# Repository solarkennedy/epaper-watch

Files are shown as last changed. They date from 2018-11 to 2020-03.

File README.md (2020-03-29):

# epaper-watch

Originally setup as a watch, this turned into a wall clock:

epaper clock (https://xkyle.com/uploads/epaper_clock.jpg)

It uses a [database of literary quotes](https://xkyle.com/epaper-watch-Cleaning-the-Literary-Quotes-Database/) to display what time it is, highlighting the quote in <font color="red">red</font>.

This project originally started as a wrist watch with battery management and a custom PCB:

epaper watch_prototype (https://xkyle.com/uploads/epaper_watch.jpg)

The wrist watch version was too ambitious and too distracting, so I gave up and just left it as a wall-clock. Originally I took inspiration from this [clock that used a kindle](https://www.instructables.com/id/Literary-Clock-Made-From-E-reader/), but wanted more control over the hardware.

## Hardware

* 2.9inch (296x128 pixels) Waveshare eink [module](https://www.waveshare.com/wiki/2.9inch_e-Paper_Module_(B))
* esp8266 development board
* Picture frame

## Software

* [Source code](https://github.com/solarkennedy/epaper-watch)
* NTP-sourced time
* Ubuntu font
* Literary quotes for (most) minute of the hour

## Usage

It isn't the most accurate or easy to read clock, but it is interesting and looks nice when it has a good quote on it.

The refresh is a bit ugly and could be improved (click for the youtube version):

epaper clock refresh (https://www.youtube.com/watch?v=ptu6fU2wjEg)

The tri-color epaper requires two refresh cycles, one to clear the screen and put down black, then a second pass for the red. See [Ben Krasnow's (Applied Science) notes](https://benkrasnow.blogspot.com/2017/10/fast-partial-refresh-on-42-e-paper.html) on these epaper displays for some interesting low-level technical details on how they work.

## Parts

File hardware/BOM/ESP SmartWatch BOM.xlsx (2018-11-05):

ESP SmartWatch Bill of Materials
Qty | Part | Value | Device | Package | MPN
10 | C1, C2, C4, C5, C6, C7, C8, C9, C10, C11 | 1u | C-USC0603 | C0603 | CL10B105MO8NNWC
7 | C3, C13, C14, C15, C20, C21, C22 | 0.1u | C-USC0603 | C0603 | CL10F104ZO8NNNC
2 | C12, C19 | 4.7u | C-USC0603 | C0603 | CL10A475KP8NNNC
4 | D1, D2, D3, D4 | MBR0530 | MBR0520LT | SOD123 | MBR0530
1 | DISP | 24FLZ-SM2-TB(LF)(SN) | 24FLZ-SM2-TB(LF)(SN) | CON24_1X24_DB_JST | 24FLZ-SM2-TB(LF)(SN)
1 | IC2 | NCP603SN330T1G | NCP603SN330T1G | SOT95P275X110-5N | NCP603SN330T1G
1 | L1 | ASPI-6045S-680M-T | ASPI-6045S-680M-T | ASPI-6045S-680M-T | ASPI-6045S-680M-T
1 | Q1 | FDV305N | MOSFET-NCH | SOT23-3 | FDV305N
1 | Q4 | ZXM61P02FTA | MOSFET-PCH | SOT23-3 | ZXM61P02FTA
1 | R1 | 3R | R-US_R0603 | R0603 | RC0603FR-073R01L
8 | R2, R3, R4, R5, R6, R7, R10, R14 | 10k | R-US_R0603 | R0603 | RC0603FR-0710KL
3 | R11, R12, R13 | 47k | R-US_R0603 | R0603 | RC0603FR-0747KL
1 | U1 | ESP-12F | ESP-12F | ESP-12F | *module*
1 | U2 | MCP73832 | MCP73832 | SOT23-5 | MCP73832T-2ACI/OT
1 | USB1 | ZX62-B-5PA | MICRO-USB-SMD(ZX62-B-5PA) | MICRO-USB | ZX62-B-5PA(33)

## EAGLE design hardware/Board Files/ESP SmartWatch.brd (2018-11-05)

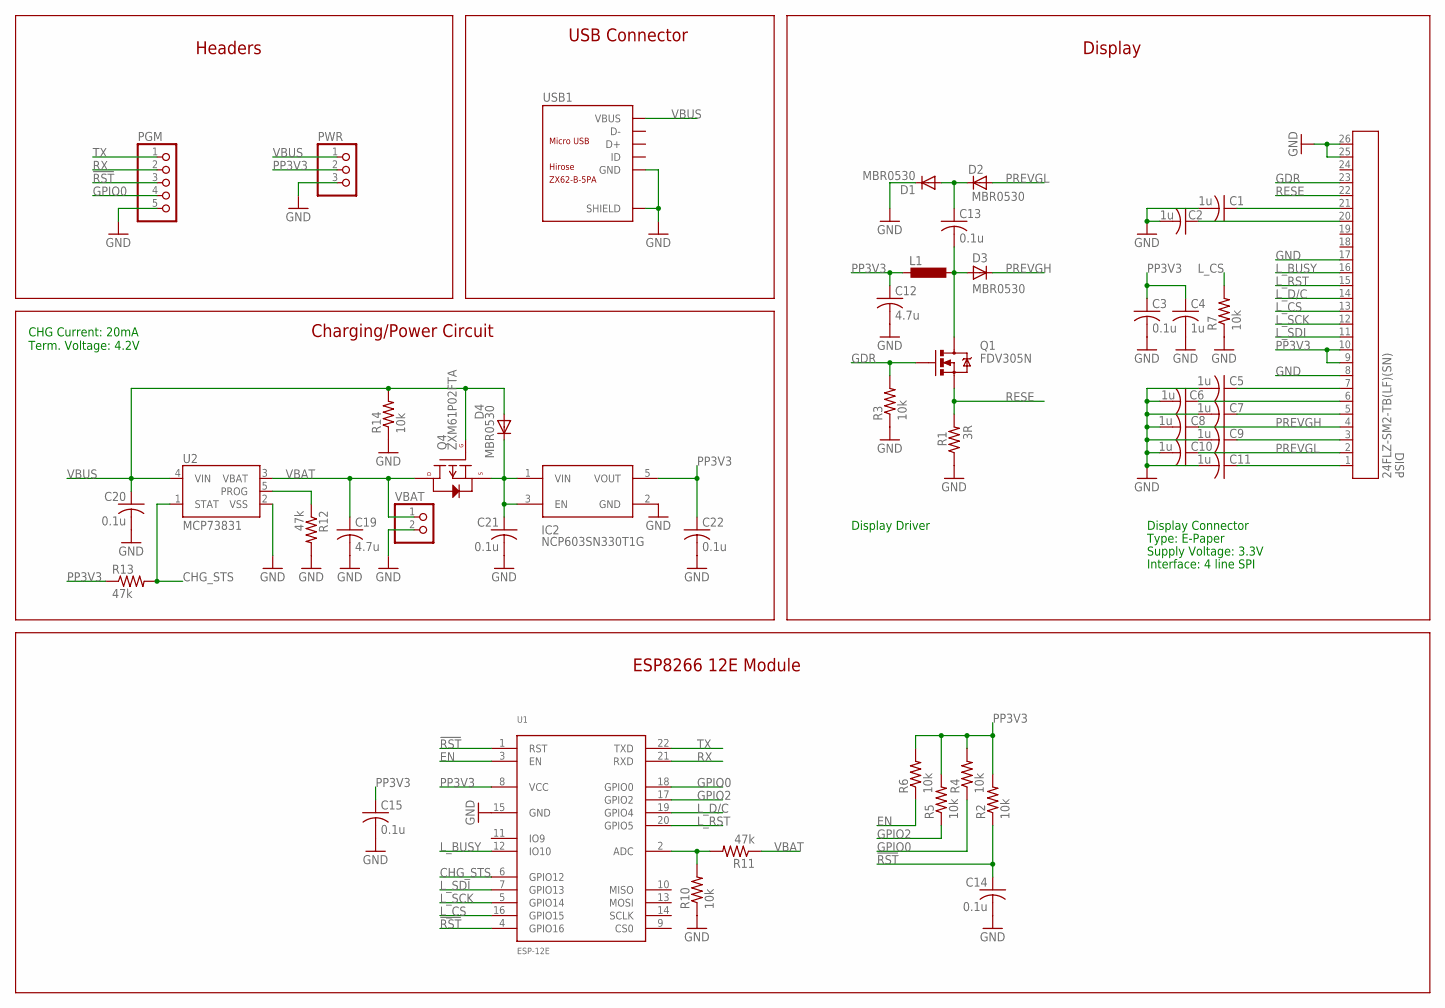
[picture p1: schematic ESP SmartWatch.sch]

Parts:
C1, C2, C4, C5, C6, C7, C8, C9, C10, C11: 1u; C0603
C3, C13, C14, C15, C20, C21, C22: 0.1u; C0603
C12, C19: 4.7u; C0603
D1, D2, D3, D4: MBR0530; SOD123
DISP: 24FLZ-SM2-TB(LF)(SN); CON24_1X24_DB_JST
IC2: NCP603SN330T1G; SOT95P275X110-5N
L1: ASPI-6045S-680M-T
PGM: PINHD-1X05_2.00; 1X05M
PWR: PINHD-1X03_2.00; 1X03M
Q1: FDV305N; SOT23-3
Q4: ZXM61P02FTA; SOT23-3
R1: 3R; R0603
R2, R3, R4, R5, R6, R7, R10, R14: 10k; R0603
R11, R12, R13: 47k; R0603
U1: ESP-12E; ESP-12F
U2: MCP73831; SOT23-5
USB1: ZX62-B-5PA; MICRO-USB5+6P-SMD-0.65-AB
VBAT: PINHD-1X02_2.00; 1X02M

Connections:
!RST: C14.1, PGM.3, R2.1, U1.1 (RST), U1.4 (GPIO16)
CHG_STS: R13.2, U1.6 (GPIO12), U2.1 (STAT)
EN: R6.1, U1.3 (EN)
GDR: DISP.23 (2323), Q1.1 (G), R3.2
GND: C1.2, C2.2, C3.2, C4.2, C5.2, C6.2, C7.2, C8.2, C9.2, C10.2, C11.2, C12.2, C14.2, C15.2, C19.2, C20.2, C21.2, C22.2, D1.C, DISP.8 (88), DISP.17 (1717), DISP.25 (2525), DISP.26 (2626), IC2.2 (GND), PGM.5, PWR.3, R1.1, R3.1, R7.1, R10.1, R12.2, R14.1, U1.15 (GND), U2.2 (VSS), USB1.5 (GND), USB1.P1 (SHIELD), USB1.P2 (SHIELD), USB1.P3_1 (SHIELD), USB1.P3_2 (SHIELD), USB1.P3_3 (SHIELD), USB1.P4_1 (SHIELD), USB1.P4_2 (SHIELD), USB1.P4_3 (SHIELD), USB1.P5 (SHIELD), USB1.P6 (SHIELD), VBAT.2
GPIO0: PGM.4, R4.1, U1.18 (GPIO0)
GPIO2: R5.1, U1.17 (GPIO2)
L_BUSY: DISP.16 (1616), U1.12 (IO10)
L_CS: DISP.13 (1313), R7.2, U1.16 (GPIO15)
L_D/C: DISP.14 (1414), U1.19 (GPIO4)
L_RST: DISP.15 (1515), U1.20 (GPIO5)
L_SCK: DISP.12 (1212), U1.5 (GPIO14)
L_SDI: DISP.11 (1111), U1.7 (GPIO13)
unnamed: C1.1, DISP.21 (2121)
unnamed: C2.1, DISP.20 (2020)
unnamed: C13.1, D1.A, D2.C
unnamed: C13.2, D3.A, L1.2, Q1.3 (D)
unnamed: R10.2, R11.2, U1.2 (ADC)
unnamed: R12.1, U2.5 (PROG)
unnamed: C21.1, D4.C, IC2.1 (VIN), IC2.3 (EN), Q4.2 (S)
unnamed: C5.1, DISP.7 (77)
unnamed: C6.1, DISP.6 (66)
unnamed: C7.1, DISP.5 (55)
unnamed: C9.1, DISP.3 (33)
unnamed: C11.1, DISP.1 (11)
PP3V3: C3.1, C4.1, C12.1, C15.1, C22.1, DISP.9 (99), DISP.10 (1010), IC2.5 (VOUT), L1.1, PWR.2, R2.2, R4.2, R5.2, R6.2, R13.1, U1.8 (VCC)
PREVGH: C8.1, D3.C, DISP.4 (44)
PREVGL: C10.1, D2.A, DISP.2 (22)
RESE: DISP.22 (2222), Q1.2 (S), R1.2
RX: PGM.2, U1.21 (RXD)
TX: PGM.1, U1.22 (TXD)
VBAT: C19.1, Q4.3 (D), R11.1, U2.3 (VBAT), VBAT.1
VBUS: C20.1, D4.A, PWR.1, Q4.1 (G), R14.2, U2.4 (VIN), USB1.1 (VBUS)

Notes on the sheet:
Display Connector
Interface: 4 line SPI
Supply Voltage: 3.3V
Type: E-Paper
Display Driver
Display
USB Connector
Charging/Power Circuit
ESP8266 12E Module
Headers
CHG Current: 20mA Term. Voltage: 4.2V

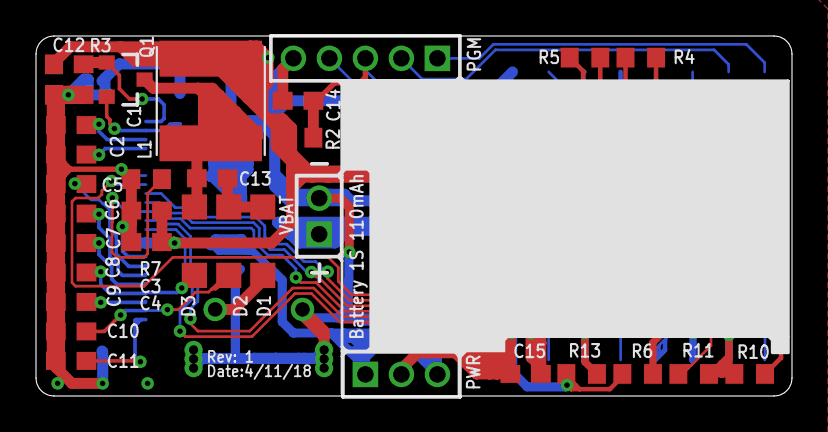
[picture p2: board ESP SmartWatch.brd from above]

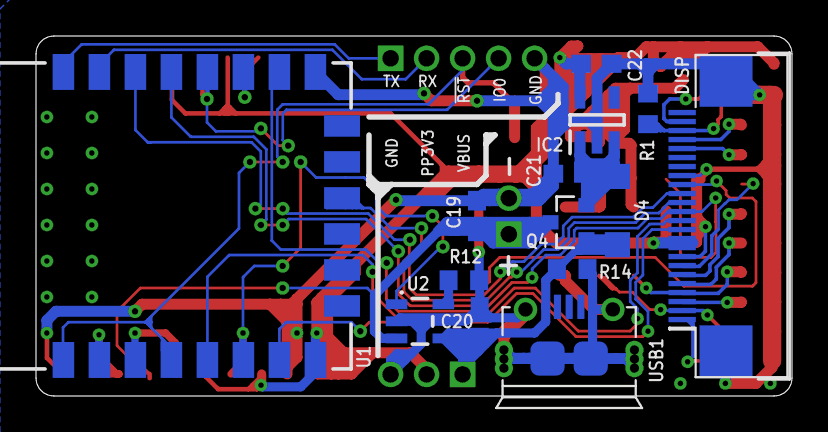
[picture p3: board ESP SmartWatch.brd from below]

Board: 2 copper layers, 42.0 x 20.0 mm, 46 parts (14 on the bottom side), 33 nets.

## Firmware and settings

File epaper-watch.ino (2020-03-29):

//#define WATCH
//#define DEV

const char compile_date[] = __DATE__ " " __TIME__;
String quote;
String attribution;


void setup(void) {
  setupSerial();
  setupClockFromRTC();
  if (isTimeDataBogus(getCurrentTime())) {
    Serial.println(F("Time is way out of sync."));
    Serial.println(F("Getting time from NTP first..."));
    if (connectToWifi(-1)) syncTimeFromWifi();
  }

  int m = getCurrentMinute();
  setQuoteForMinute(m);
#ifdef DEV
  if (quote == "") {
    setQuoteToCurrentTime();
  }
#endif

  Serial.print(F("The quote for this minute ("));
  Serial.print(m);
  Serial.println(F(") is:"));
  Serial.println(quote);
  Serial.println(attribution);
  if (quote != "") {
    setupEpaper();
  }

  if (isTimeDataBogus(getCurrentTime())) {
    Serial.println(F("Time is way out of sync."));
    Serial.println(F("Getting time from NTP first..."));
    if (connectToWifi(-1)) syncTimeFromWifi();
  } else {
    syncIfItIsAGoodTime();
  }
  saveTimeAndSleep();
}

void syncIfItIsAGoodTime() {
  Serial.println(F("syncIfItIsAGoodTime..."));
#ifdef WATCH
  if (getMinuteOfTheHour() == 0) {
#else
  if (getMinuteOfTheHour() % 5 == 0) {
#endif
    Serial.println(F("Now is the right time to opportunistically sync ntp"));
    if (connectToWifi(-1)) syncTimeFromWifi();
  }
}

void setupSerial() {
  Serial.begin(115200);
  Serial.println();
  Serial.println();
  Serial.println();
  Serial.printf("ESP8266 Chip id = %08X\n", ESP.getChipId());
  Serial.printf("Sketch compiled %s\n", compile_date);
}

void loop(void) {
}

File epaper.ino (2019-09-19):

#ifdef WATCH
#include <GxEPD2_BW.h>
GxEPD2_BW<GxEPD2_213_flex, GxEPD2_213_flex::HEIGHT> display(GxEPD2_213_flex(/*CS=15*/ SS, /*DC=4*/ 4, /*RST=5*/ 5, /*BUSY=16*/ 16)); // GDEW0213I5F
#else
#include <GxEPD2_3C.h>
GxEPD2_3C<GxEPD2_290c, GxEPD2_290c::HEIGHT> display(GxEPD2_290c(/*CS=D8*/ SS, /*DC=D3*/ 4, /*RST=D4*/ 5, /*BUSY=D2*/ 16));
#endif

#include "Ubuntu_B7pt7b.h"


void setupEpaper() {
  Serial.println(F("setupEpaper..."));
  initEpaper();
  display.firstPage();
  do
  {
    Serial.println(F("nextPage loop..."));
#ifdef WATCH
    displayBatteryMeter(readBatteryLevel());
#endif
    displayQuote();
    displayAttribution();
  }
  while (display.nextPage());
#ifdef WATCH
  display.hibernate();
#endif
}

void displayQuote() {
  Serial.println(F("displayQuote..."));
  int str_len = quote.length() + 1;
  char char_array[str_len];
  quote.toCharArray(char_array, str_len);
  char *p = char_array;
  char *w;
  int x;
  int y;
  int16_t tbx, tby; uint16_t tbw, tbh;
  bool bold = false;

  while ((w = strtok_r(p, " ", &p)) != NULL)
  {
    if (w[0] == '*') {
      if (bold == false) {
        bold = true;
#ifdef WATCH
        display.setTextColor(GxEPD_BLACK, GxEPD_WHITE);
#else
        display.setTextColor(GxEPD_RED, GxEPD_WHITE);
#endif
      } else {
        bold = false;
#ifdef WATCH
        display.setTextColor(GxEPD_BLACK, GxEPD_WHITE);
#else
        display.setTextColor(GxEPD_BLACK, GxEPD_WHITE);
#endif
      }
      continue;
    }
    // If we are going to overflow the line we need to wrap
    x = display.getCursorX();
    y = display.getCursorY();
    display.getTextBounds(w, x, y, &tbx, &tby, &tbw, &tbh);

    if (tbx == 1 && x != 0) {
      // If we are going to overflow the line we need to wrap
      display.println();
      Serial.println();
    } else if (y > display.height() ) {
      Serial.println("We've overflowed the screen!");
      display.println();
      Serial.println();
    }

    display.print(w);
    Serial.print(w);
    display.print(" ");
    Serial.print(" ");
  }
  Serial.println();
}

void initEpaper() {
  Serial.println(F("initEpaper..."));
  display.init(0, true);
  display.setRotation(3);
  setFont();
  display.fillScreen(GxEPD_WHITE);
}

void displayAttribution() {
  Serial.println(F("displayAttribution..."));
  int16_t tbx, tby; uint16_t tbw, tbh;
  display.getTextBounds(attribution, 0, 0, &tbx, &tby, &tbw, &tbh);
  uint16_t x = (display.width() - tbw - 6);
  uint16_t y = (display.height() - tbh + 10);
  display.setCursor(x, y);
  display.println(attribution);
}

void setFont()
{
  const GFXfont* f = &Ubuntu_B7pt7b;
  display.setTextColor(GxEPD_BLACK, GxEPD_WHITE);
  display.setFont(f);
  display.setCursor(0, 12);
}

uint8_t readBatteryLevel() {
  float voltage = readBatteryVoltage();
  uint8_t percent = sigmoidal(voltage, 3.2, 4.1);
  Serial.print(F("Battery Percent: "));
  Serial.print(percent);
  Serial.print(" (");
  Serial.print(voltage);
  Serial.println(" volts)");
  return percent;
}

float readBatteryVoltage() {
  float raw = rawBatteryAnalogRead();
  Serial.print("Raw analog read is: ");
  Serial.println(raw);
  const float ref = 1.0;
  const float adjust = 0.875609756; // shrug?
  float vout = (raw * ref * adjust) / 1023.0;
  Serial.print("Voltage at the A0 pin: ");
  Serial.print(vout);
  Serial.println(" volts");
  float R1 = 47000.0;
  float R2 = 10000.0;
  float vin = vout / (R2 / (R1 + R2));
  Serial.print("Computed voltage read is: ");
  Serial.print(vin);
  Serial.println(" volts");
  return vin;
}

float rawBatteryAnalogRead() {
  return analogRead(A0);
}

void displayBatteryMeter(uint8_t percent) {
  int h = round(display.height() * percent / 100);
  display.fillRect(display.width() - 1, display.height() - h , 1, h, GxEPD_BLACK);
}


static inline uint8_t sigmoidal(float voltage, float minVoltage, float maxVoltage) {
  Serial.println(voltage);
  Serial.println(minVoltage);
  Serial.println(maxVoltage);
  uint8_t result = 105 - (105 / (1 + pow(1.724 * (voltage - minVoltage) / (maxVoltage - minVoltage), 5.5)));
  Serial.println(result);
  return result >= 100 ? 100 : result;
}

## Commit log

2018-10-01 codegen phase 1 for lit stuff
    [litclock_annotated.csv]
2018-10-02 Working on both avr and esp32
2018-10-14 real printing and csv cleanup
    [litclock_annotated.csv]
2018-10-28 more csv changes and stuff
    [litclock_annotated.csv]
2018-10-28 Ensure all csv time strings exist
    [litclock_annotated.csv]
2018-10-28 Sanitize attribution string
    [litclock_annotated.csv]
2018-11-04 Some power management
    [litclock_annotated.csv]
2018-11-04 Working epaper driver port
2018-11-05 Added hardware files
    [ESP SmartWatch BOM.xlsx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]
2018-11-11 More lit tweaks
    [litclock_annotated.csv]
2019-01-01 Working battery meter
2019-02-24 Set the quote to the current time when there is none
2019-02-25 More wifi ntp sync + power optimiziations
2019-03-30 Removed extra spaces from csv
    [litclock_annotated.csv]
2019-03-30 Massive cleanup on the lit csv
    [litclock_annotated.csv]
2019-03-31 Massive editing of the quote database
    [litclock_annotated.csv]
2019-03-31 No quotes more than 180 characters
    [litclock_annotated.csv]
2019-03-31 Replace non-ascii chars out of the csv
    [litclock_annotated.csv]
2019-04-01 More accurate battery reading
2019-05-27 Duplicate out all the quotes that have ambiguous AM/PM
    [litclock_expanded_meridiem.csv]
2019-05-27 Expand the lit database to include am/pm duplicates for real
    [litclock_expanded_meridiem.csv]
2019-09-18 Massive quote fixes
    [litclock_annotated.csv, litclock_expanded_meridiem.csv]
2019-09-19 Lots of quote fixes
    [litclock_expanded_meridiem.csv]
2019-09-19 Fix DEV and WATCH mode
    [epaper-watch.ino, epaper.ino]
